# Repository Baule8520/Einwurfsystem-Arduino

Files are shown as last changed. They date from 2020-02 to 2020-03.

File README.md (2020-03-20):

# Einwurfsystem
Aufbau einer elektrischen Steuerung für ein Einwurfsystem, beispielsweise einer Rückgabeklappe für Bücher.

Die Software wurde von mir schrittweise zusammengebaut. Ich habe Sie in 5 Teilbereiche zerlegt, um die jeweilige Funktion der Komponente genau verstehen zu können: 

1. Ethernet Funktionalität herstellen (Ethernet_)
2. WebServer Funktionen testen (WebServer_)
3. Real Time Clock (RTC_)
4. Schrittmotor Ansteuerung (Schrittmotor_)
5. Der sogenannte Master, also das Hauptprogramm, in dem alles zusammen läuft (Master_)

Die verwendete Hardware war ein Arduino UNO mit aufgestecktem Ethernet Shield Version 2.
Dementsprechend muss die Arduino IDE zum Kompilieren und Uploaden installiert sein.

Anbei sind außerdem die von mir verwendeten Libraries (libraries)

Ausführliche Dokumentation unter: https://wiki.tum.de/pages/viewpage.action?pageId=394625561

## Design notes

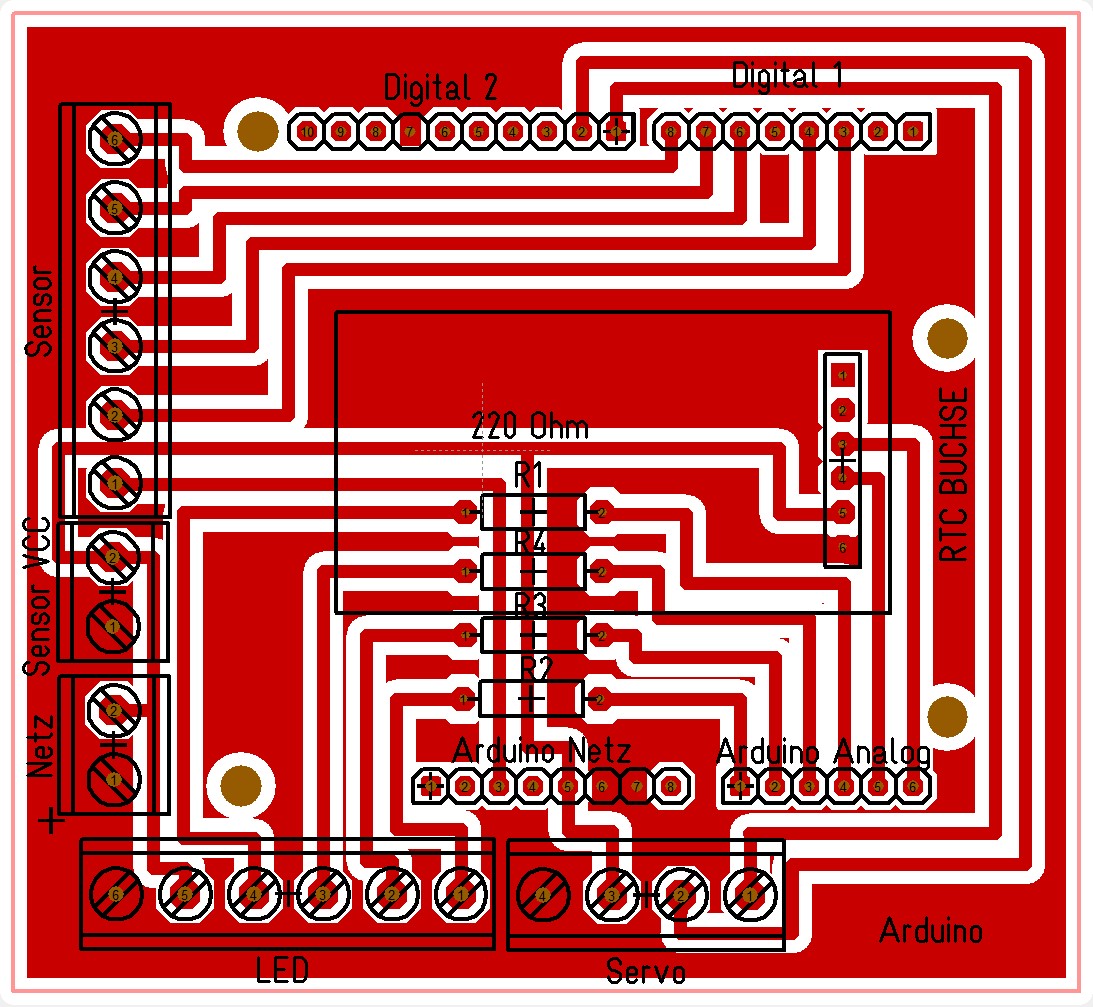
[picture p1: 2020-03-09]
Platine/Platine.jpg

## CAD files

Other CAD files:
Demo-Kasten/Deckel Fusion360.f3d
Demo-Kasten/Demo Kasten Fusion360.f3d
Demo-Kasten/Gewicht + Führung Fusion360.f3d
Demo-Kasten/Scharnier Fusion360.f3d

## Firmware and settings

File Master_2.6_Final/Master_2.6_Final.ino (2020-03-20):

/*
  Programm Einwurfsystem

  By Paul Zech

  Version 2.6:
  - Überprüfen ob Methodenaufruf notwendig
  - Kleinere Fehler und Korrekturen
 */


#include <SPI.h>                                            // SPI Controller
#include <Ethernet.h>                                       // Ethernet Funktionalität
#include <Servo.h>                                          // Servo Funktion
#include "RTClib.h"                                         // RTC Library: https://github.com/adafruit/RTClib --> Kann über Strg + Umschalt + I im Manager hinzugefügt werden


byte mac[] = {0xA8, 0x61, 0x0A, 0xAE, 0x42, 0xD7};          // MAC Adresse des Ethernet Shield hier eintragen
IPAddress ip(192, 168, 188, 10);                            // Freie IP-Adresse hier eintragen
EthernetServer server(80);                                  // Ethernet Port hier eintragen, für HTTP ist 80 der Standardport
String readString;                                          // Erstellen eines String in dem die Kommunikation mit dem Client gespeichert wird

Servo servo;                                                // Name des Servo Motors
RTC_DS3231 RTC;                                             // RTC Board auswählen und benennen

byte SensorKlappe = 2;                                      // Anschluss des Sensors für die Klappe, also offen oder geschlossen (Sicherheitsfunktion)
byte SensorServoZu = 3;                                     // Anschluss des Sensors für die Endposition (geschlossen) des Motors (Statusüberwachung)
byte SensorServoOffen = 5;                                  // Anschluss des Sensors für die Endposition (geöffnet) des Motors (Statusüberwachung)
byte SensorEinwurf = 6;                                     // Anschluss des Sensors für die Zahl der eingeworfenen Gegenstände
byte SensorReset = 7;                                       // Anschluss des Sensors für den manuellen Reset der eingeworfenen Gegenstände
//byte freierInOut = 8;                                     // Anschluss als Reserve, noch nicht belegt und der letzte freie Anschluss am Board

byte LampeFehler = 14;                                      // Anschluss Kontrollampe für den Fehlerfall (Ein == Fehler)
byte LampeServo = 15;                                       // Anschluss Kontrolllampe für Servoanschlag (Ein == Klappe ist zu)
byte LampeAuto = 16;                                        // Anschluss Kontrollampe für Automatische Steuerung (Ein == Klappe wäre bei automatischer Steuerung offen)
byte LampeAutoIO = 17;                                      // Anschluss Kontrollampe ob Automatik aktiviert oder deaktiviert ist (Ein == Automatik aktiv)

bool Automatik = 1;                                         // Automatischen Modus aktivieren / deaktivieren
bool ZustandAutomatik = 1;                                  // Zustand der automatischen Steuerung (Klappe offen / geschlossen)
bool Fehler = 0;                                            // Gibt an ob ein Fehler aufgetreten ist
int Eingeworfen = 0;                                        // Anzahl der eingeworfenen Gegenstände
int EingeworfenInsgesamt = 0;                               // Anzahl der eigeworfenen Gegenstände seit letztem Boot
bool Prello = 0;                                            // Zwischenspeicher zum Entprellen der Taste der eingeworfenen Gegenstände
byte Auf = 127;                                             // Servo Position Offen (Zwischen 0 und 180 Grad)
byte Zu = 15;                                               // Servo Position Geschlossen (Zwischen 0 und 180 Grad)
byte Tag;                                                   // Variablen speichern die Zeit des letzten Reboots ab
byte Monat;
int Jahr;
byte Stunde;
byte Minute;


void setup() {

  servo.attach(9, 2, 1520);                                                         // Anschlusspin des Servos, Minimale und Maximale Frequenz in Microsekunden
  pinMode(SensorKlappe, INPUT_PULLUP);                                              // Sensoren als Input mit Pull Up Widerstand klassifizieren
  pinMode(SensorEinwurf, INPUT_PULLUP);
  pinMode(SensorServoZu, INPUT_PULLUP);
  pinMode(SensorServoOffen, INPUT_PULLUP);
  pinMode(SensorReset, INPUT_PULLUP);
  
  pinMode(LampeServo, OUTPUT);                                                      // LEDs als Output klassifizieren
  pinMode(LampeFehler, OUTPUT);
  pinMode(LampeAuto, OUTPUT);
  pinMode(LampeAutoIO, OUTPUT);
  
  Serial.begin(9600);                                                               // Seriellen Monitor Starten --> Debugging
  while (!Serial) { ; }
  Serial.println(F("Einwurfsystem 2.6\n"));                                         // Titel des Programms am seriellen Monitor ausgeben
  
  if (! RTC.begin()) {                                                              // Fehlermeldung: Kein RTC Modul
    Serial.println(F("RTC Modul nicht vorhanden"));
    while (1);}
  if (RTC.lostPower()) {
    Serial.println(F("RTC Modul hat die Zeit verloren, wird neu eingestellt!"));    // Hinweis: Zeit wurde eingestellt nachdem Modul ohne Strom
    RTC.adjust(DateTime(F(__DATE__), F(__TIME__)));}
    
  DateTime now = RTC.now();
  Tag = now.day();                                                                  // Speichert die Zeit des letzten Reboots ab                                
  Monat = now.month();
  Jahr = now.year();
  Stunde = now.hour();
  Minute = now.minute();

  Ethernet.begin(mac, ip);                                                          // Start des Ethernet Zugriffs

  if (Ethernet.hardwareStatus() == EthernetNoHardware) {                            // Fehlermeldung: Kein Ethernet Shield
    Serial.println(F("Ethernet Shield nicht aufgesteckt"));
    while (true) {
      delay(1); }}
  if (Ethernet.linkStatus() == LinkOFF) {                                           // Fehlermeldung: Keine Netzwerk Verbindung
    Serial.println(F("Kein Netzwerkkabel eingesteckt"));}
  
  server.begin();                                                                   // Start des Servers
  Serial.print(F("Server befindet sich auf "));
  Serial.println(Ethernet.localIP());                                               // IP Adresse des Servers ausgeben
  Serial.print(F("\n"));
}


void loop() {                                                                             

  EthernetClient client = server.available();                                           // Nach neuem Client suchen

  int Einwurf = digitalRead(SensorEinwurf);                                             // Sensor Abfrage: Einwurf (Pull Up: Standartsensorwert == 1)
  int Klappe = digitalRead(SensorServoZu);                                              // Sensor Abfrage: Zustand Endanschlag (Pull Up: Standartsensorwert == 1)
  int ResetE = digitalRead(SensorReset);

  if (Klappe == 1) {                                                                    // Gibt den Zustand der Klappe (offen / geschlossen) an der LED aus
              digitalWrite(LampeServo, HIGH);}
  if (Klappe == 0) {
              digitalWrite(LampeServo, LOW);}
   
  if (Einwurf == 0 && Prello == 0) {                                                    // Zählt bei Einwurf == 0 den Eingeworfen nach oben
              Eingeworfen += 1;
              EingeworfenInsgesamt += 1;
              Prello = 1;}
  if (Einwurf == 1 && Prello == 1) {                                                    // Entprellt die Taste um eine halbe Sekunde --> Hier anpassen, je nach Sensortyp
              delay(100);
              Prello = 0;}
  if (ResetE == 0) {Eingeworfen = 0;}                                                   // Zurücksetzten des Zählers durch Sensor (Schalter)

  if (Fehler == 1) {digitalWrite(LampeFehler, HIGH);}                                   // Fehler Lampe einschalten, wenn ein Fehler passiert ist
  
  if (Automatik == 1) {                                                                 // Wenn die Automatik läuft, dann...
    
    digitalWrite(LampeAutoIO, HIGH);                                                    // Kontrollampe Automatikmodus einschalten
    DateTime now = RTC.now();
      
      if (now.dayOfTheWeek() == 0 && digitalRead(SensorServoOffen) == 0)  {             // Sonntag (Amerikanisches System: 0 == Sonntag, 1 == Montag, ...)
          ServoWriteAuf();                                                              // An Tagen an denen die Klappe immer offen sein braucht man nur den Tag, keine Uhrzeit
          digitalWrite(LampeAuto, HIGH);
          ZustandAutomatik = 1;}
  
      if (now.dayOfTheWeek() == 1) {                                                    // Montag (Unterhalb kann man die Öffnungszeiten eintragen, in diesem Fall von 10:00 bis 12:59:59 und von 16:00 bis 18:59:59)
          if (now.hour() == 10 || now.hour() == 11 || now.hour() == 12 || now.hour() == 15 || now.hour() == 16 || now.hour() == 17 || now.hour() == 18) {
            if (digitalRead(SensorServoZu) == 0) {
              ServoWriteZu();                                                             
              digitalWrite(LampeAuto, LOW);
              ZustandAutomatik = 0;}}
          else if (digitalRead(SensorServoOffen) == 0) {
            ServoWriteAuf();
            digitalWrite(LampeAuto, HIGH);
            ZustandAutomatik = 1;}}
          
      if (now.dayOfTheWeek() == 2 && digitalRead(SensorServoOffen) == 0)  {             // Dienstag
           ServoWriteAuf();
           digitalWrite(LampeAuto, HIGH);
           ZustandAutomatik = 1;}
      
      if (now.dayOfTheWeek() == 3)  {                                                   // Mittwoch
        if (now.hour() == 10 || now.hour() == 11 || now.hour() == 12 || now.hour() == 13 || now.hour() == 14 || now.hour() == 15 || now.hour() == 16 || now.hour() == 17) {
            if (digitalRead(SensorServoZu) == 0) {
              ServoWriteZu();
              digitalWrite(LampeAuto, LOW);
              ZustandAutomatik = 0;}}
          else if (digitalRead(SensorServoOffen) == 0) {
            ServoWriteAuf();
            digitalWrite(LampeAuto, HIGH);
            ZustandAutomatik = 1;}}

       if (now.dayOfTheWeek() == 4)  {                                                  // Donnerstag
          if (now.hour() == 15 || now.hour() == 16 || now.hour() == 17) {
            if (digitalRead(SensorServoZu) == 0) {
              ServoWriteZu();
              digitalWrite(LampeAuto, LOW);
              ZustandAutomatik = 0;}}
          else if (digitalRead(SensorServoOffen) == 0) {
            ServoWriteAuf();
            digitalWrite(LampeAuto, HIGH);
            ZustandAutomatik = 1;}}
          
       if (now.dayOfTheWeek() == 5)  {                                                   // Freitag
          if (now.hour() == 10 || now.hour() == 11 || now.hour() == 12 || now.hour() == 15 || now.hour() == 16 || now.hour() == 17 || now.hour() == 18) {
            if (digitalRead(SensorServoZu) == 0) {
              ServoWriteZu();
              digitalWrite(LampeAuto, LOW);
              ZustandAutomatik = 0;}}
          else if (digitalRead(SensorServoOffen) == 0) {
            ServoWriteAuf();
            digitalWrite(LampeAuto, HIGH);
            ZustandAutomatik = 1;}}
          
      if (now.dayOfTheWeek() == 6 && digitalRead(SensorServoOffen) == 0)  {              // Samstag
            ServoWriteAuf();
            digitalWrite(LampeAuto, HIGH);
            ZustandAutomatik = 1;}}

  if (Automatik == 0) {digitalWrite(LampeAutoIO, LOW);}                                             
 
  if (client) {                                                                         // Wenn Client gefunden, dann...    
    
    Serial.println(F("Neuer Client verfügbar"));
    
    while (client.connected()) {
     
      if (client.available()) {

        DateTime now = RTC.now();                                                       // Liest aktuelle Uhrzeit im Moment der HTTP Abfrage aus
        char X = client.read();                                                         // Speichert die ankommenden Daten (jeweils nur ein Zeichen) im Zeichen (8bit) "X"
        if (readString.length() < 100) {                                                // Speichert den ganzen Request im String bis zu einer Länge von 100
          readString += X;}

        if (X == '\n') {                                                                // Wenn eine leere Zeile ankommt (Signalisiert das Ende eines HTTP Request)
                           
          client.println("HTTP/1.1 200 OK");                                            // Inhalt der "Website" --> HTML Header
          client.println("Content-Type: text/html");
          client.println();
          
          client.println("<!DOCTYPE HTML>");                                            // Inhalt der "Website" --> HTML Content
          client.println("<html>");
          client.println("<head>");
          client.println("<title>Steuerung</title>");
          client.println("</head>");
          client.println("<body>");
          client.println("<h1>Einwurfsystem</h1><br />");
          
          client.println(F("Letzte Aktualisierung um "));                               // Gibt die Zeit der letzten Aktualisierung der Website aus
          client.print(now.hour(), DEC);
          client.print(':');
          client.print(now.minute(), DEC);
          client.print(':');
          client.print(now.second(), DEC);
          client.print(" am ");
          client.print(now.day(), DEC);
          client.print('.');
          client.print(now.month(), DEC);
          client.print('.');
          client.print(now.year(), DEC);          
          client.println("<br /><br />");

          client.println(F("Bitte nach jeder Aktion unterhalb und um den aktuellen Status einzusehen die Seite aktualisieren: "));
          client.println("<a href=\"/?1aktual\"\">Aktualisieren</a><br /><br /><br />"); // Schaltfläche Aktualisieren --> ohne Aktion, lädt nur die Seite neu

          if (Fehler == 1) {                                                             // Ausgabe im Fehlerfall
            client.println(F("Es ist ein Fehler im Schliessmechanismus aufgetreten, bitte ueberpruefen und das System anschliessend am Geraet per Schalter resetten!<br /><br /><br />"));}
          
          client.print("<a href=\"/?1auto\"\">Automatische</a>");                        // href Verlinkung um Aktion auszuführen 
          client.print(" oder ");
          client.print("<a href=\"/?1manu\"\">Manuelle</a>");                            // href Verlinkung um Aktion auszuführen
          client.print(" Steuerung<br /><br />");
          
          if (Automatik == 0) {
            client.println("<a href=\"/?1auf\"\">Klappe Auf</a>");                       // href Verlinkung um Aktion auszuführen 
            client.print(" oder ");
            client.println("<a href=\"/?1zu\"\">Klappe Zu</a><br /><br />");}            // href Verlinkung um Aktion auszuführen

          client.println(F("Status Automatikmodus: Klappe ist "));                       // Zeigt an, ob die Automatik die Klappe öffnen oder sperren würde
            if (ZustandAutomatik == 1) {
              client.println("offen");}
            if (ZustandAutomatik == 0) {
              client.println("zu");}
          client.println("<br /><br />");

          client.println(F("Status aktuell: Klappe ist "));                              // Gibt den aktuellen Zustand der Klappe aus, basierend auf dem Sensor Wert
            if (Klappe == 0) {
              client.println("offen");}
            if (Klappe == 1) {
              client.println("zu");}
          client.println("<br /><br /><br />");
          
          client.println(F("Eingeworfene Gegenstaende: "));                              // Gibt die Anzahl von "Eingeworfen" aus
          client.println(Eingeworfen);
          client.println("  -->  ");
          client.println("<a href=\"/?1reset\"\">Reset des Zaehlers</a><br /><br />");   // Schaltfläche Reset des Zählers 

          client.println(F("Letzter Systemneustart war um "));                           // Gibt die Zeit des letzten Systemneustarts aus
          client.print(Stunde);
          client.print(':');
          client.print(Minute);
          client.print(" am ");
          client.print(Tag);
          client.print('.');
          client.print(Monat);
          client.print('.');
          client.print(Jahr);
          client.println(F(", seitdem eingeworfene Gegenstaende: "));                    // Gibt die Anzahl von "EingeworfenInsgesamt" aus
          client.println(EingeworfenInsgesamt);
          client.println("<br /><br /><br />");
          
          client.println(F("Systemtemperatur: "));                                       // Nett to know: Eine Temparaturanzeige des DS3231 Boards :-)
          client.print(RTC.getTemperature());
          client.println(" C");
          
          client.println("</body>");
          client.println("</html>");                                                     // Ende der HTML Informationen
          
          Serial.println(F("Daten abgesendet"));                                         // Information über erfolgreiche Sendung am seriellen Monitor

          delay(2);                                                                      // Warten bis Client Daten empfangen hat
    
          client.stop();                                                                 // Verbindung beenden

          if (readString.indexOf("?1auf") > 0){                                          // Servo auffahren, anhand von href im ankommenden HTTP String
              ServoWriteAuf(); }
               
          if (readString.indexOf("?1zu") > 0){                                           // Servo Zufahren, anhand von href im ankommenden HTTP String
              ServoWriteZu(); }  
                 
          if (readString.indexOf("?1reset") > 0){                                        // Reset des Zählers der eingeworfenen Gegenstände
                Eingeworfen = 0;
               Serial.println(F("Reset des Zählers"));} 

          if (readString.indexOf("?1auto") > 0){                                         // Automatik aktivieren
               Automatik = 1;
               Serial.println(F("Automatik aktiviert"));}
               
          if (readString.indexOf("?1manu") > 0){                                         // Automatik deaktivieren
                Automatik = 0;
               Serial.println(F("Automatik deaktiviert"));}       
               
          readString = "";                                                               // String entleeren
          }
      }
    }
    Serial.println(F("Verbindung geschlossen\n\n"));
  }
}


void ServoWriteAuf() {                                                                  // Methode zum Servo öffnen
  if (digitalRead(SensorKlappe) == 0) { 
     servo.write(Auf);
     Serial.println(F("Klappe Auf"));
     delay(1000);
      if (digitalRead(SensorServoOffen) == 0) {                                         // Wenn Klappe nicht innerhalb von 1 Sekunde offen ist --> Fehler
         Fehler = 1; }}}


void ServoWriteZu(){                                                                    // Methode zum Servo schließen
  if (digitalRead(SensorKlappe) == 0) { 
     servo.write(Zu);
     Serial.println(F("Klappe Zu"));
     delay(1000);
      if (digitalRead(SensorServoZu) == 0) {                                            // Wenn Klappe nicht innerhalb von 1 Sekunde zu ist --> Fehler
        Fehler = 1; }}}

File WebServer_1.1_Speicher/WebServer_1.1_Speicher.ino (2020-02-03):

/*
  WebServer zur Steuerung eines Servos, Abfragen eines Sensors und Speicherung von Daten

  By Paul Zech

  Version 1.1
 
 */


#include <SPI.h>                                            // SPI Controller
#include <Ethernet.h>                                       // Ethernet Funktionalität
#include <Servo.h>                                          // Servo Funktion


byte mac[] = {0xA8, 0x61, 0x0A, 0xAE, 0x42, 0xD7};          // MAC Adresse des Ethernet Shield hier eintragen
IPAddress ip(192, 168, 188, 10);                            // Freie IP-Adresse hier eintragen
EthernetServer server(80);                                  // Ethernet Port hier eintragen, für HTTP ist 80 der Standardport
String readString;                                          // Erstellen eines String in dem die Kommunikation mit dem Client gespeichert wird
Servo servo;                                                // Name des Servo Motors
int SensorKlappe = 6;                                       // Anschluss des Sensors für die Klappe
int SensorEinwurf = 7;                                      // Anschluss des Sensors für die eingeworfenen Gegenstände
int Kontrolllampe = 2;                                      // Anschluss Kontrolllampe
int Klappe = digitalRead(SensorKlappe);                     // Sensor Wert der Klappe initial abspeichern
int Eingeworfen = 0;                                        // Anzahl der eingeworfenen Gegenstände auf 0 setzen
int Einwurf = 1;                                            // Zwischenspeicher 1 zum Entprellen der Taste der eingeworfenen Gegenstände
int Prello = 0;                                             // Zwischenspeicher 2 zum Entprellen der Taste der eingeworfenen Gegenstände

void setup() {

  servo.attach(5);                                          // Anschluss des Servos
  pinMode(SensorKlappe, INPUT_PULLUP);                      // Sensor als Input mit Pull Up Widerstand klassifizieren
  pinMode(SensorEinwurf, INPUT_PULLUP);
  pinMode(Kontrolllampe, OUTPUT);

  Serial.begin(9600);                                       // Seriellen Monitor Starten --> Debugging
  while (!Serial) { ; }
  
  Serial.println("WebServer Version 1.1\n");                // Titel des Programms ausgeben

  Ethernet.begin(mac, ip);                                  // Start des Ethernet Zugriffs

  if (Ethernet.hardwareStatus() == EthernetNoHardware) {    // Fehlermeldung: Keine Hardware
    Serial.println("Ethernet Shield nicht aufgesteckt");
    while (true) {
      delay(1); }}
  if (Ethernet.linkStatus() == LinkOFF) {                   // Fehlermeldung: Kein Kabel
    Serial.println("Kein Netzwerkkabel eingesteckt");}
  
  server.begin();                                           // Start des Servers
  Serial.print("Server befindet sich auf ");
  Serial.println(Ethernet.localIP());                       // IP Adresse des Servers ausgeben
  Serial.print("\n");
}


void loop() {                                                                             

  EthernetClient client = server.available();                            // Nach neuem Client suchen
      int Einwurf = digitalRead(SensorEinwurf);
   
    if (Einwurf == 0 && Prello == 0) {
              Eingeworfen += 1;
              Prell = 1;
              Prello = 1;}
    if (Einwurf == 1 && Prello == 1) {
              delay(250);
              Prello = 0;}

              
  if (client) {                                                          // Wenn Client gefunden, dann...    
    
    Serial.println("Neuer Client verfügbar");


    
    while (client.connected()) {
     
      if (client.available()) {
        
        char X = client.read();                                          // Speichert die ankommenden Daten (jeweils nur ein Zeichen) im Zeichen (8bit) "X"
        int Klappe = digitalRead(SensorKlappe);                          // Sensor Wert wird im Moment der Abfrage ausgelesen
        
        if (readString.length() < 100) {                                 // Speichert den ganzen Request bis im String bis zu einer Länge von 100
          readString += X;
          }

        if (X == '\n') {                                                 // Wenn eine leere Zeile ankommt (Signalisiert das Ende eines HTTP Request --> nicht ganz optimal, da ja auch davor leere Zeilen vorkommen)
                           
          client.println("HTTP/1.1 200 OK");                             // Inhalt der "Website" --> Header
          client.println("Content-Type: text/html");
          client.println();
          
          client.println("<!DOCTYPE HTML>");                             // Inhalt der "Website" --> Content
          client.println("<html>");
          client.println("<head>");
          client.println("<title>Steuerung</title>");
          client.println("</head>");
          client.println("<body>");
          client.println("<h1>Test - Steuerung Einwurfkasten</h1>");
          client.println("<br />");
          client.println("<br />");
          client.println("<br />");
          client.println("<a href=\"/?1auf\"\">Klappe Auf</a>");   
          client.println("<br />");
          client.println("<br />");
          client.println("<a href=\"/?1zu\"\">Klappe Zu</a><br />"); 
          client.println("<br />");
          client.println("<br />");
          client.println("Status: Klappe ist ");                         // Gibt den aktuellen Zustand der Klappe aus, basierend auf dem Sensor Wert
            if (Klappe == 1) {
              client.println("offen");
              digitalWrite(Kontrolllampe, LOW);}
            if (Klappe == 0) {
              client.println("zu");
              digitalWrite(Kontrolllampe, HIGH);}
          client.println("<br />");
          client.println("<br />");
          client.println("Eingeworfene Gegenstaende: "); 
          client.println(Eingeworfen);
          client.println("</body>");
          client.println("</html>");
          
          Serial.println("Daten abgesendet");                            // Information über erfolgreiche Sendung am seriellen Monitor

          delay(2);                                                      // Warten bis Client Daten empfangen hat
    
          client.stop();                                                 // Verbindung beenden

          if (readString.indexOf("?1auf") > 0){                          // Servo auffahren
               servo.write(40);
               Serial.println("Klappe Auf");
           }
           if (readString.indexOf("?1zu") > 0){                          // Servo Zufahren
                servo.write(170);
               Serial.println("Klappe Zu");
           }    
           
          readString = "";                                               // String entleeren
          
          }
      }
    }
    
    Serial.println("Verbindung geschlossen\n\n");
    
  }
}

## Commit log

2020-02-03 Kleine Fehler in der Dokumentation behoben
    [Ethernet_Interaction_Check_1.1.ino, Master_1.1_Timing.ino, Master_1.3_Troubleshoot.ino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]
2020-02-06 Troubleshoot vom 06.02.2020
    Die Variable "Zu" wurde doppelt verwendet, deswegen funktionierte der Servo nicht mehr. Ich dachte dabei an einen Hardware defekt. Dabei ist der Fehler so einfach lösbar...
2020-02-19 Finale Version 2.2
    Einige Features hinzugefügt, Optimierungen durchgeführt und Fehler behoben.
    [Master_2.2_Verbesserungen.ino]
2020-02-22 Neuer starker Servo + kleinere Optimierungen
    Einen neuen stärkeren Servo mit abweichenden Frequenzen eingebunden (dazu wird ein Netzteil benötigt), außerdem kleinere Programmverbesserungen die mir im laufenden Test aufgefallen sind.
2020-03-06 2.4 und 2.5 neu
    Version 2.4:
    - Bugfix (Entprellung)
    - Änderungen an der Verkabelung
    - Neuer Sensor integriert
    - Neue LED integriert
    Version 2.5:
    - Aufruf von Methoden für das Servo öffnen und schließen
    - Fehlermeldungen ausgeben und speichern
    [Master_2.4_AnpassungHardware.ino, Master_2.5_Methoden.ino]
2020-03-09 Arduino Shield (Platine)
    Platinen G-Code, Werkzeugliste und Target Datei
2020-03-09 Demo-Kasten
    .f3d Dateien des Demo Kastens
    Außerdem Bild von der Platine hinzugefügt.
    [Deckel Fusion360.f3d, Demo Kasten Fusion360.f3d, Gewicht + Führung Fusion360.f3d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]
